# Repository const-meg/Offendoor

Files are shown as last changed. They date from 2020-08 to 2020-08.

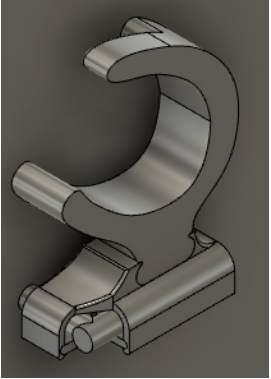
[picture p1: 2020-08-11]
montadoenpuerta.PNG

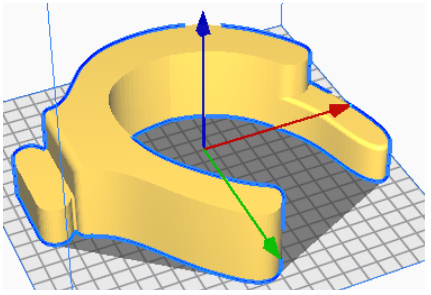
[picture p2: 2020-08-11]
impresionbrazo.PNG

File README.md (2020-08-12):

# Offendoor
Proyecto del curso Seminario de Diseño e Innovación tecnológica: “Interfaz de activación adaptable, intuitivo, ergonómico higiénico, esteril para abrir puertas de manera touchless para personal médico de UCI”

En el contexto de la pandemia que se enfrenta globalmente a causa del coronavirus ha surgido la necesidad de proteger a lo actores de primera línea, tanto médicos, enfermeros, personal médico y de aseo en zona UCI de hospitales que a pesar de los distintos protocolos de protección personal implementado a la fecha aun se ven enfrentados día a día a un alto riesgo de contagio al estar en un contacto continuo y estrecho con pacientes que padecen la enfermedad.

Se ha identificado que además del contagio vía aérea y para lo cual sirven de forma efectiva las mascarillas existe la posibilidad de contagio a través del contacto de zonas infectadas con ojos, nariz y boca, es sabido que el contacto entre las mano y la cara es frecuente, difícil de evitar y muchas veces inconsciente. Es por esto que es indispensable mantener las manos limpias en todo momento, tanto para la protección del mismo individuo como la protección de otros al evitar la expansión del virus sobre otras superficies.

Al hacer una exploración digital de distintas zona UCI, así como el comportamiento de los distintos actores que interactúan dentro de ella, se descubre que el elemento en común entre todas ellas, que utiliza contacto directo con las manos y que es utilizado por todos son las puertas a las habitaciones de pacientes. El protocolo actual requiere el uso de guantes y el lavado de manos antes y después del contacto con pacientes lo cual visto en la larga escala se traduce a una gran cantidad de cambio de guantes por día y pérdida de valioso tiempo en acciones tan simples como abrir una puerta, es por esto que se propone como medida adicional la creación de un dispositivo que permita abrir las puertas sin contacto.

Se define como objetivo diseñar una “Interfaz de activación adaptable, intuitivo, ergonómico higiénico, esteril para abrir puertas de manera touchless para personal médico de UCI”. Una “interfaz de activación” ya que se trata de un dispositivo intermedio entre el usuario y el mecanismo de apertura de la puerta; “adaptable” ya que al hablar de puertas es fácil reconocer la diversidad de modelos existentes y en uso, lo que hace necesario que el diseño tenga en consideración una variedad de posibilidades; “intuitivo” el tiempo es un recurso escaso cuando se habla del tratamiento de pacientes; es por eso que queremos que el usuario requiera el menor tiempo posible en entender el funcionamiento del dispositivo y lo utilice tan simplemente como lo haría con una puerta convencional; “ergonómico” éste está ligado al punto anterior, se busca hacer la experiencia de uso cómoda para el usuario; e “higiénico y esteril” al estar inserto en el contexto de la zonas UCI debe poder someterse a los rigurosos protocolos de limpieza a las que se ven sometidas las distintas superficies allí encontradas.

A partir de esta necesidad es que surge el diseño de una interfaz que facilita la apertura de las puertas utilizando el codo, de esta manera tenemos que el mecanismo que utilizaremos se compone de un soporte a la manilla y de un brazo que puede extraerse y lavarse con facilidad. De esta manera se tiene que el dispositivo en cuestión cumple con las características previamente planteadas, y que además facilita su implementación en cualquier parte del mundo, ya que fue diseñado de manera tal que su fabricación sea completamente a través de la impresión 3D. Adicionalmente, el dispositivo tiene todas sus partes para ser montadas al momento de la impresión, sin la necesidad de tornillos u otro tipo de dispositivos adicionales. 

El dispositivo consta de 4 partes como se muestra en la Figura 1.a, las cuales son imprimibles y están diseñadas de tal manera que toda la impresión se realice de manera tal que no tenga mucho trabajo de post procesos, ya que casi no se genera material de soporte al momento de realizar la impresión. Adicionalmente podemos ver que las piezas se unen a través de sistemas de encajes deslizantes.

depieceversionfinal
versionfinal

Figura 1: a) Despiece de la solución propuesta, compuesta de 4 partes (soporte, brazo y 2 tapas). b) Conjunto completo una vez armado.

Esta solución está diseñada para una manilla como la mostrada en la Figura 2.a, la cual es una manilla en forma de L, donde las dimensiones se especifican más abajo, en la Figura 2.b. Se decidió utilizar este tipo de manillas ya que en la información recopilada en hospitales y clínicas de Chile, junto con conversaciones con otros profesionales del área de la salud pudimos encontrar que este tipo de manillas son las más utilizadas en este tipo de ambientes.

modelomanilla
medidamanilla
montadoenpuerta

Figura 2: a) Tipo de manilla utilizada para diseñar, en forma de L. b) Dimensiones de la manilla utilizada para diseñar. c) Conjunto armado y montado en la manilla del tipo L

El material con el cual se debe realizar la impresión del conjunto es un plástico PLA, para poder imprimir en impresoras que no requieren camas térmicas. Adicionalmente, se recomienda que las piezas sean impresas como se muestra en la Figura 3 para cada una de las piezas, de esta manera se evita generar material de soporte y el postproceso es mínimo.

impresionbase
impresionbrazo
impresiontapas

Figura 3: a) Soporte en la posición de impresión sugerida. b) Brazo en la posición de impresión sugerida. c) Tapas del soporte en la posición sugerida.

El brazo debe imprimirse con una escala de 0.95, al igual que las tapas, para que las piezas calcen cómodamente. En la impresión del soporte se generará material de soporte. Para que su remoción sea más fácil se sugiere que se configure el soporte tal y como se muestra en la Figura 4.a, además, se sugieren las otras configuraciones mostradas en la Figura 4.b

calidadyperimetro
configcura

Figura 4: Configuración en Ultimaker Cura a) soportes, b) calidad y perímetro.
La configuración debe ser para cada una de las impresoras utilizadas, las que se proponen son para una impresora Anet A8, pero para cada una de las impresoras se deben conocer cuales son los ángulos soportados por la impresora y cuales son los tamaños de impresión.

El montaje en la puerta es en tres pasos:

1)Montar el soporte, acomodandolo en la manilla para que queden ambas caras apoyadas.
2)Colocar las tapas en la parte inferior del soporte, fijandolo a la manilla
3)Colocar el brazo al soporte. El brazo se puede retirar para realizar lavados.

Por último para hacer uso correcto del dispositivo, tan solo se debe posicionar el antebrazo de forma horizontal y colocar el codo en la apertura destinada para ello, luego realizar un movimiento firme y controlado hacia al lado y hacia abajo siguiendo la trayectoria natural de la apertura del codo, una vez desbloqueado el mecanismo de cerradura de la puerta se tira/empuja según corresponda el sentido de apertura de la puerta, se libera el codo del dispositivo y se procede a continuar como de costumbre.

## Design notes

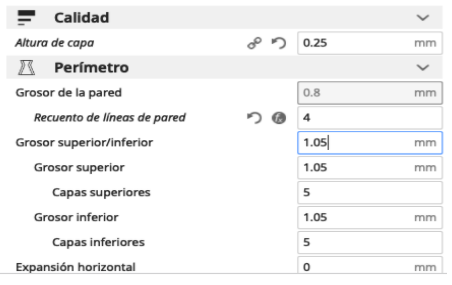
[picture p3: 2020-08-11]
calidadyperimetro.PNG

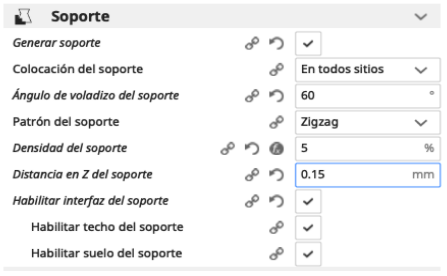
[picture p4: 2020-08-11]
configcura.PNG

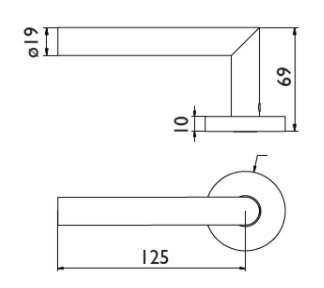
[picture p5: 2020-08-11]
medidamanilla.PNG

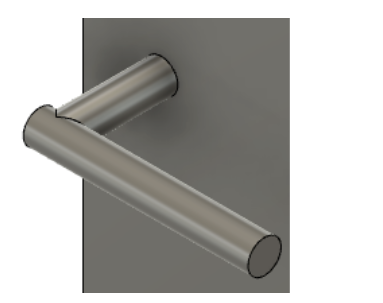
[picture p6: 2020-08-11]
modelomanilla.PNG

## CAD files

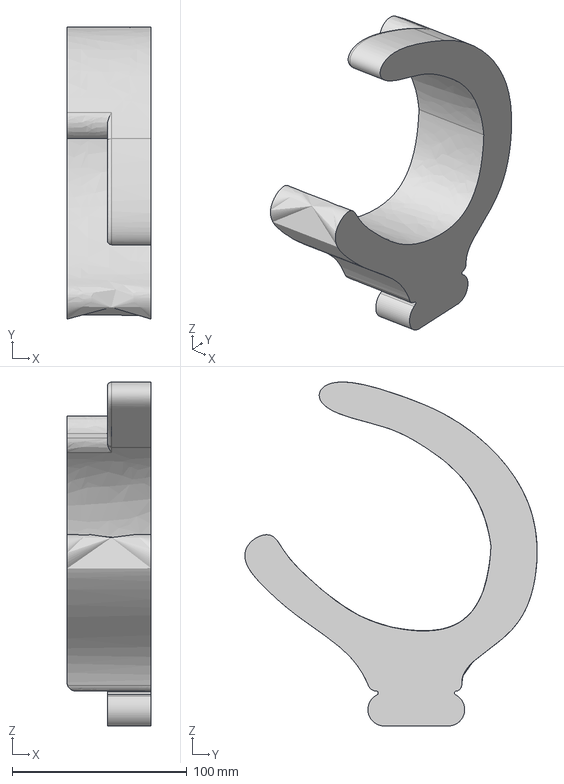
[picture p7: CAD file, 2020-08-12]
Piezas_step/brazo.step
48.0 x 167.1 x 196.7 mm

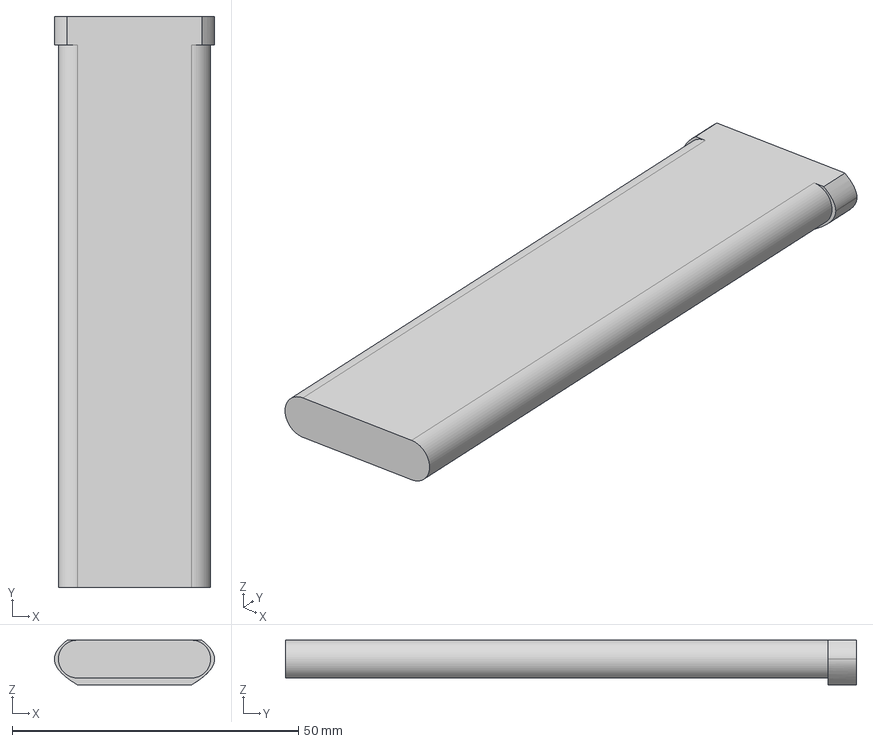
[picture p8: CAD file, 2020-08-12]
Piezas_step/tapa_larga.step
28.0 x 99.8 x 7.80 mm

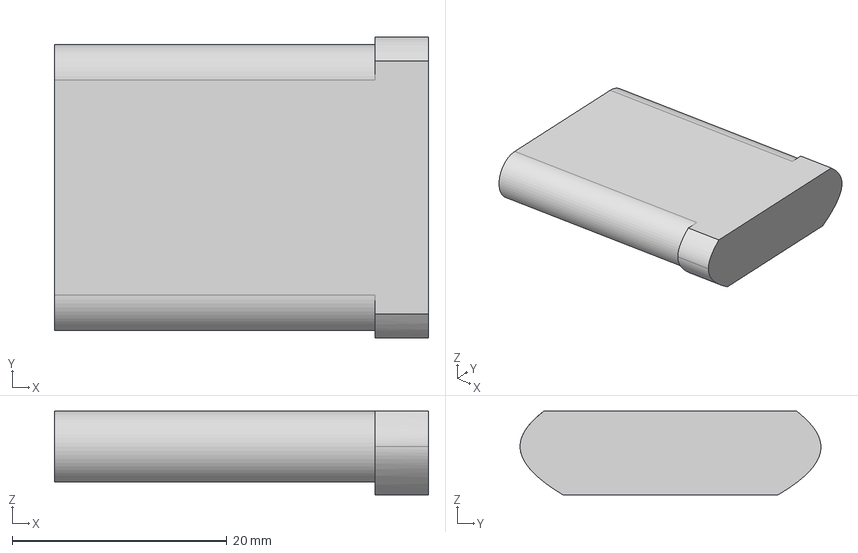
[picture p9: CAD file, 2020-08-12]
Piezas_step/tapa_corta.step
34.8 x 28.0 x 7.80 mm

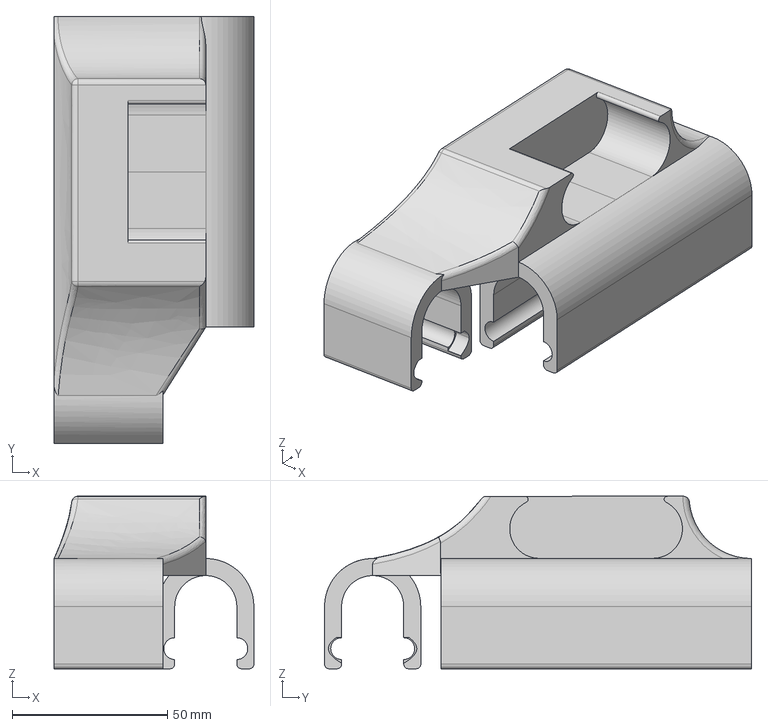
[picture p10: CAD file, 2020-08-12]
Piezas_step/soporte.step
64.3 x 137.4 x 55.5 mm

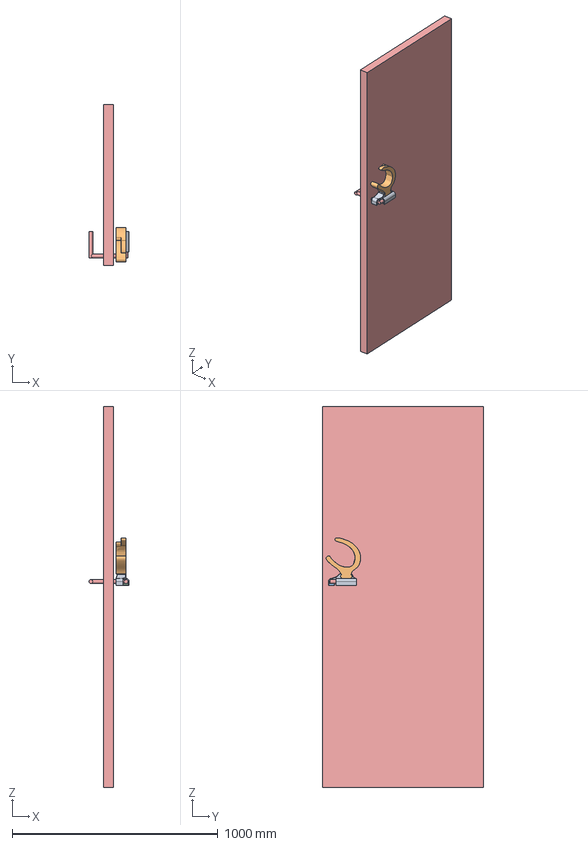
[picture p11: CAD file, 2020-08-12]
Piezas_step/Segunda Entrega v4.step
195.5 x 780.0 x 1850.0 mm

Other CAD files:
Piezas_nativas/Offendoor.f3d
Piezas_nativas/Soporte.f3d
Piezas_nativas/brazo.f3d
Piezas_nativas/tapa_corta.f3d
Piezas_nativas/tapa_larga.f3d
Piezas_stl/Soporte.stl
Piezas_stl/brazo.stl
Piezas_stl/tapa_corta.stl
Piezas_stl/tapa_larga.stl
